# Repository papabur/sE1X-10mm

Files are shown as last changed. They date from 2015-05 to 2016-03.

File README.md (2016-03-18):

# sE1X-10mm
E1X (super) with lulz bed and 10mm smooth rods

First off, thank you Tjb1 for creating the E1X and for LoH's contributions such as making the required modifications to
allow for the Lulzbot 300x300mm heated bed and also for the upgraded 10mm smooth rod designs.

I have made a few modifications that I needed to allow for the lulzbot heated bed build to work on 10mm smooth rods(I was
the first one to actually do this upgrade, I ran int oa few snags..). The first one I ran into was the Y smooth rod holders
seemed to be roughly 2mm shy in the Y axis direction and I could not get the smooth rod to mount properly so I lengthened 
those, worked perfectly for me. Second, The added height from the 10mm smooth rods required a larger Y belt gripper, so I
made a padded version that adds 5mm to it so the belt runs smoothly.

I am selling kits of the sE1X on the Mobious website and will also be selling Crunch filament, along with MKS Sbase v1.2 smoothie-compatible control boards.

If your interested please visit http://mobious.org for more information.

(2016-03-18)UPDATE: 
1: Now featuring the Open X and the Open Y carriage designs that utilize 605zz bearings at 45 degree angles around a 10mm smooth rod for the smoothest ride imaginable!@
2: DUAL EXTRUDER VERSION NOW AVAILABLE!

I have made a new BoM for the sE1X broke down into 3 sections: Hardware - Printed Parts - Fasteners. I will have links
below.

Hardware and total costs: https://goo.gl/y2NCM3

Printed Parts:            https://goo.gl/c972AP

Fasteners:                https://goo.gl/F7yG47

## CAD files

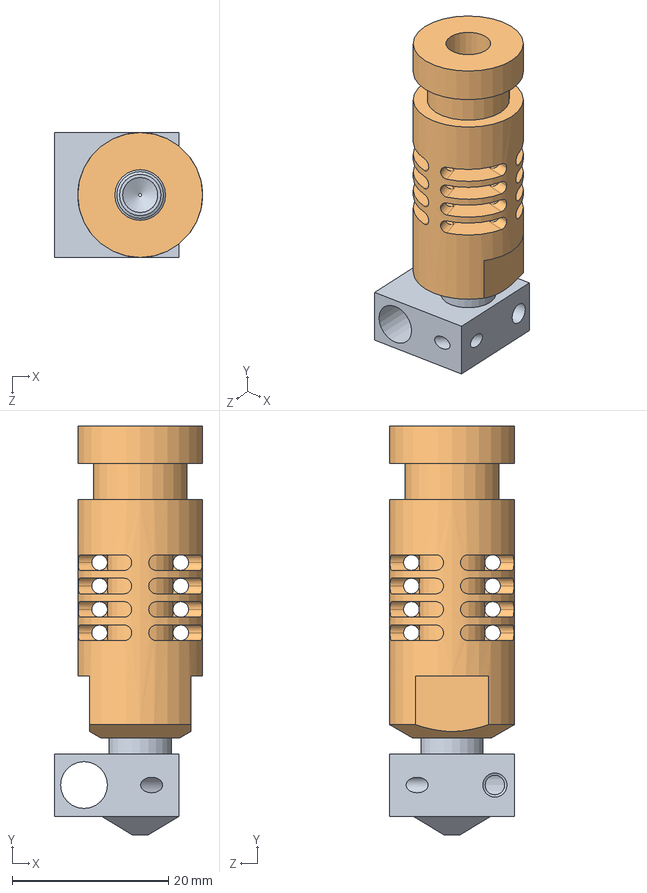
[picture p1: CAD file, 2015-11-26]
sE1X E Axis Printed Parts/JHead_Nozzle.SLDASM
19.0 x 52.4 x 16.0 mm
Part1^JHead_Nozzle
Part2^JHead_Nozzle

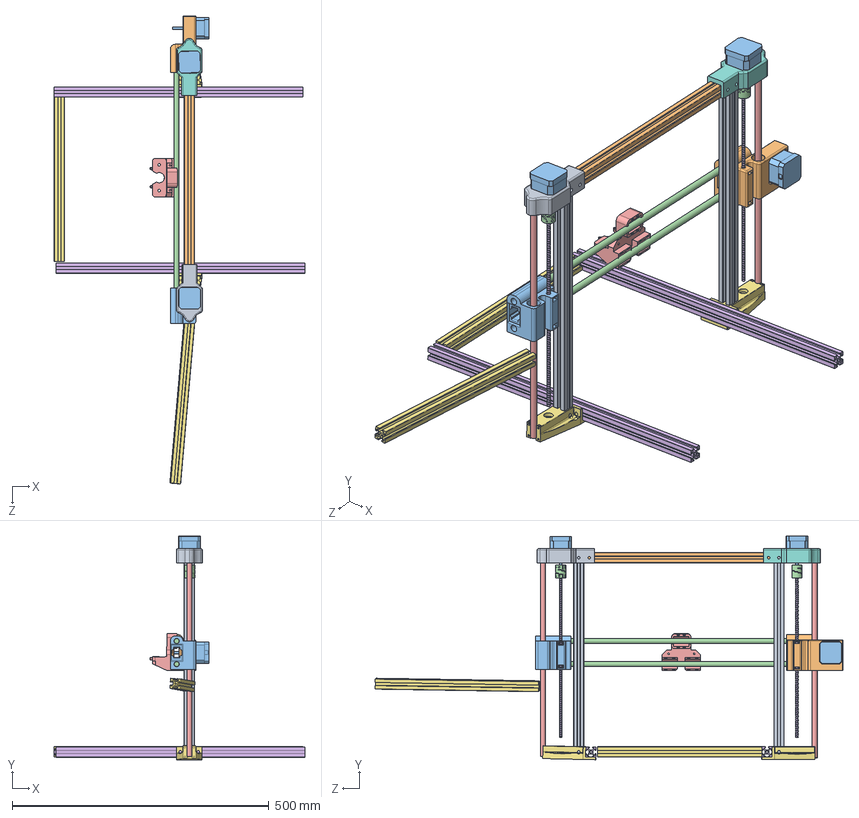
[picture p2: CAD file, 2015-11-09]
sE1X Gantry Assembly.SLDASM
488.2 x 435.6 x 911.8 mm
sE1X 398mm Z axis 2020 extrusion x 2
370mm X axis 2020 extrusion
nema17 x 3
5mm coupler x 2
sE1X 398mm 10mm smooth rod x 2
5mm threaded rod x 2
sE1X Z Axis bottom bracket x 2
sE1X Z Axis top motor bracket(mirrored)
sE1X Z Axis top motor bracket
sE1X X Axis Motor end
sE1X X idler end
sE1X 465mm 10mm smooth rod x 2
SE1X 10mm carriage(BOWDEN)
sE1X 485mm Z axis 2020 extrusion x 2
320mm X axis 2020 extrusion x 2

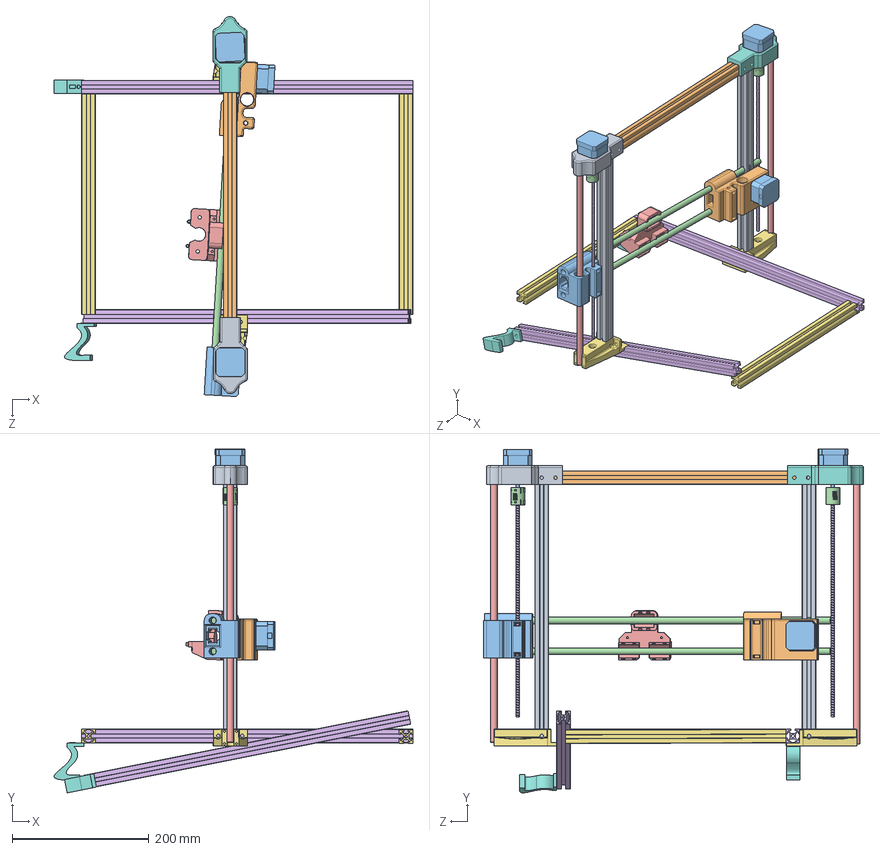
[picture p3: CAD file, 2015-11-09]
sE1X Complete Assembly.SLDASM
525.2 x 503.4 x 556.3 mm
sE1X 398mm Z axis 2020 extrusion x 2
370mm X axis 2020 extrusion
nema17 x 3
5mm coupler x 2
sE1X 398mm 10mm smooth rod x 2
5mm threaded rod x 2
sE1X Z Axis bottom bracket x 2
sE1X Z Axis top motor bracket(mirrored)
sE1X Z Axis top motor bracket
sE1X X Axis Motor end
sE1X X idler end
sE1X 465mm 10mm smooth rod x 2
SE1X 10mm carriage(BOWDEN)
sE1X 485mm Z axis 2020 extrusion x 2
320mm X axis 2020 extrusion x 2
Printer Supports -sE1X x 2

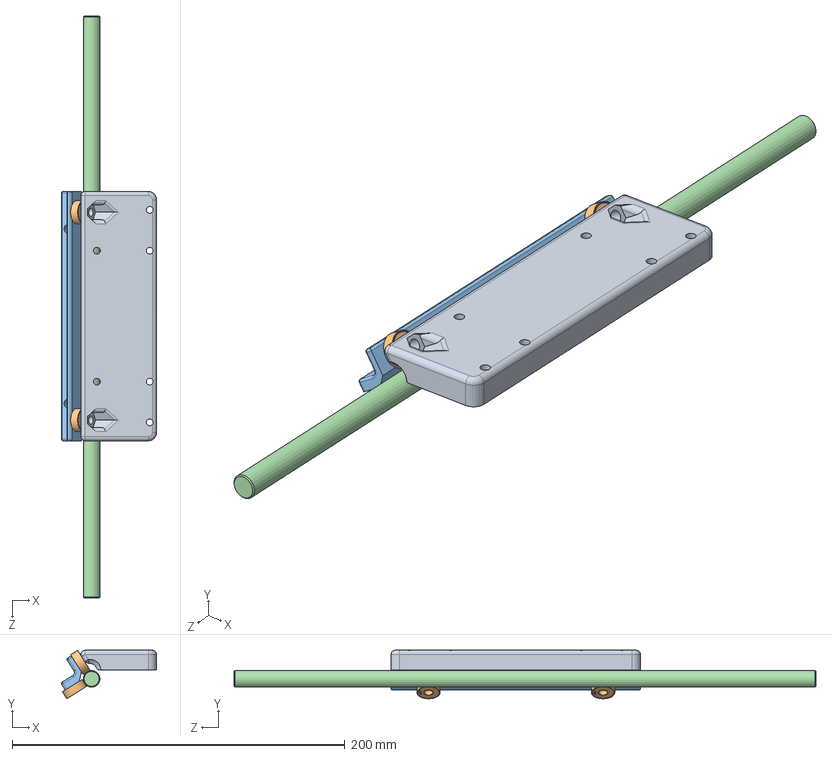
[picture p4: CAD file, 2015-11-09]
sE1X Y Axis Printed Parts/sE1X OpenY carriage ass.SLDASM
57.2 x 29.2 x 350.0 mm
sE1X OpenY carriage
605Z Ball bearing x 4
sE1X OpenY carriage side bracket(x2)
Z Axis 10mm smooth rod

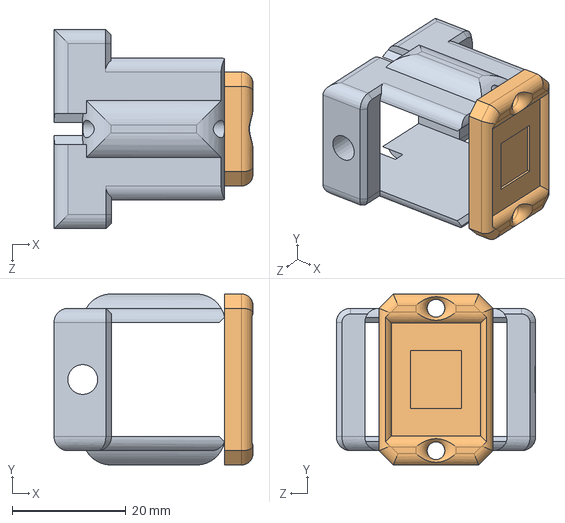
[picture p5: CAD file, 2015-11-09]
sE1X Y Axis Printed Parts/sE1X Y idler tensioner assembly.SLDASM
34.9 x 30.0 x 35.0 mm
sE1X Y idler
sE1X Y idler t-bracket

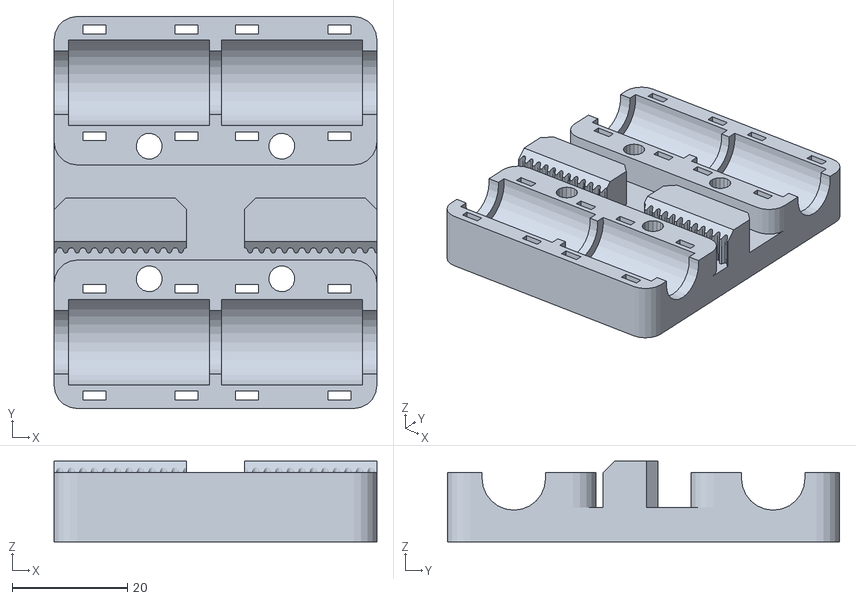
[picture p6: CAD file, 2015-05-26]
i3 Rework/X-CARRIAGE.stl
56.0 x 68.0 x 14.0

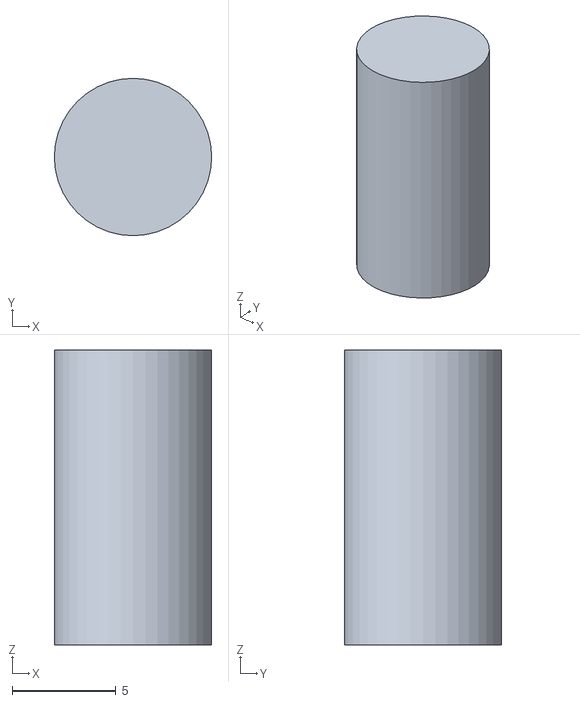
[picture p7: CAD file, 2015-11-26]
sE1X E Axis Printed Parts/Airtripper_Bowden_Extruder_BSP_Edition/axle.stl
7.60 x 7.60 x 14.2

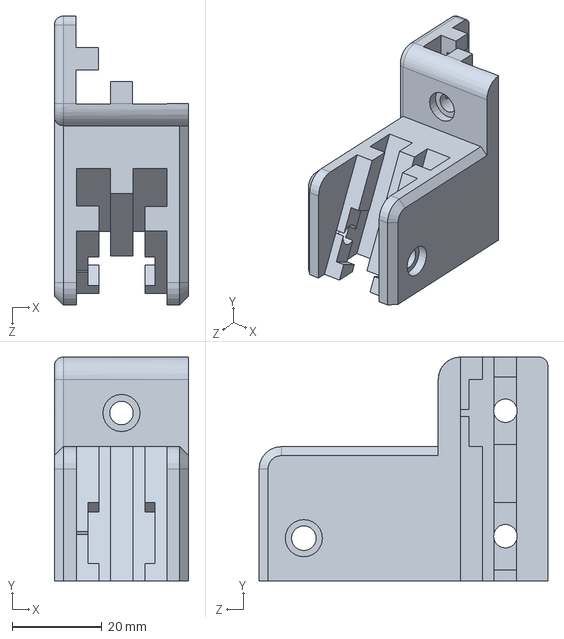
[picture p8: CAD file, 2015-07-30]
sE1X Gantry Supports/sE1X Gantry Support Z Axis Brace (L).SLDPRT
30.0 x 50.0 x 64.5 mm

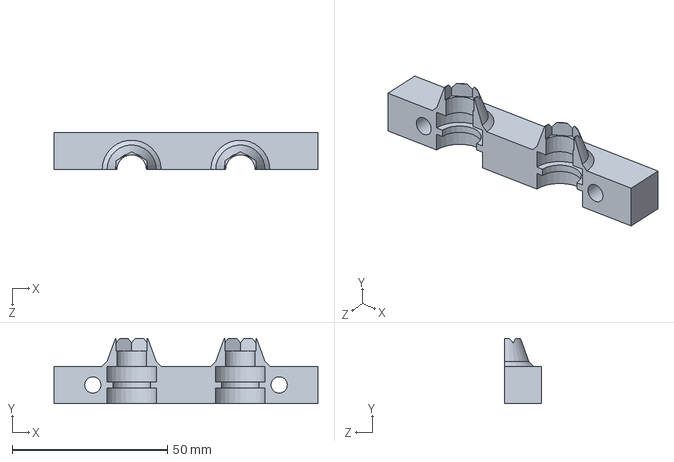
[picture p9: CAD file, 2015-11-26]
sE1X X Axis Printed Parts/OpenX Dual hotend bracket(1of2).SLDPRT
85.0 x 21.0 x 12.0 mm

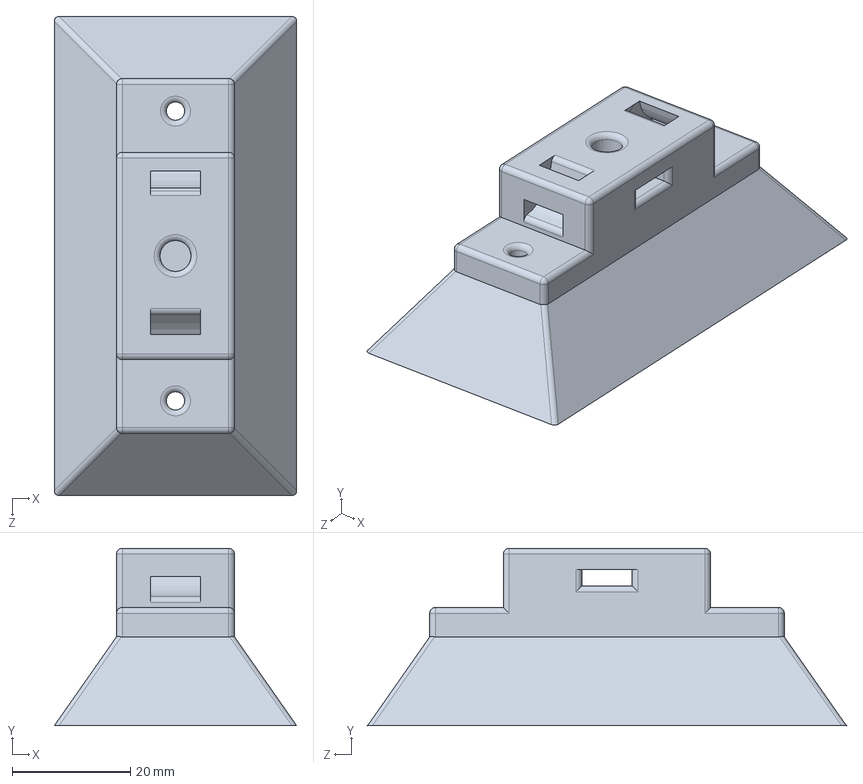
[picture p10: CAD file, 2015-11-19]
sE1X Y Axis Printed Parts/sE1X Y Belt Gripper.SLDPRT
41.0 x 30.0 x 81.0 mm

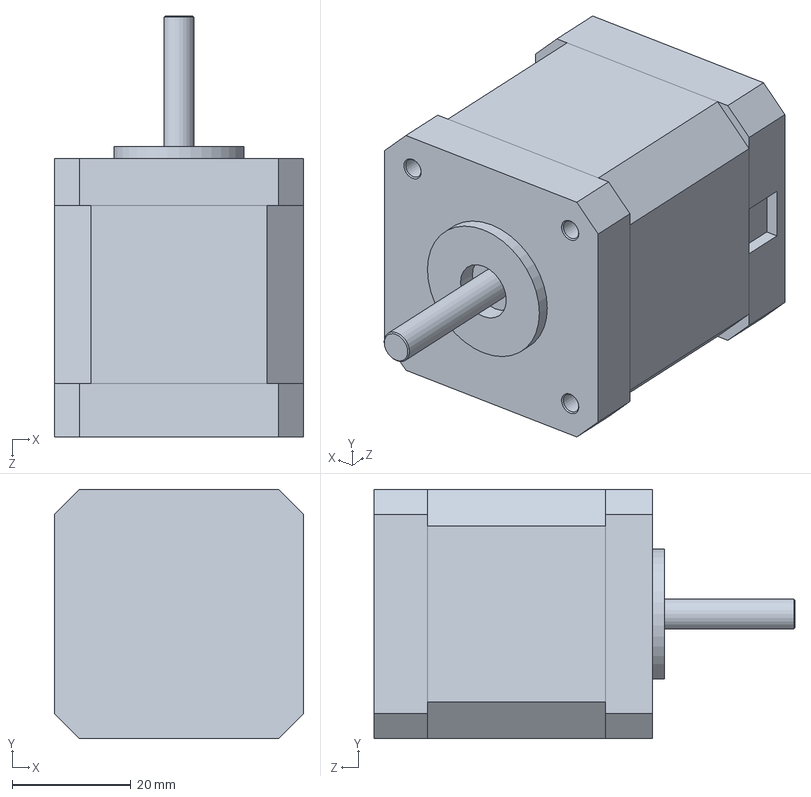
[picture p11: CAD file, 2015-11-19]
sE1X Z Axis Printed Parts/nema17.SLDPRT
42.0 x 42.0 x 71.0 mm

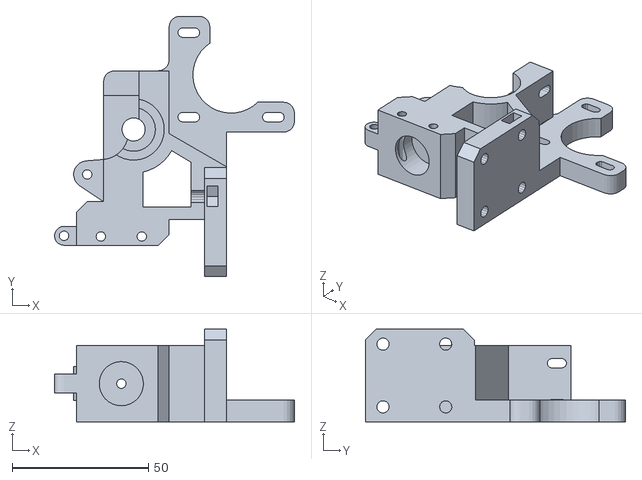
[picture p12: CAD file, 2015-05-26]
i3 Rework/BODY-EXTRUDEUR-WADE.stl
88.0 x 95.5 x 34.0

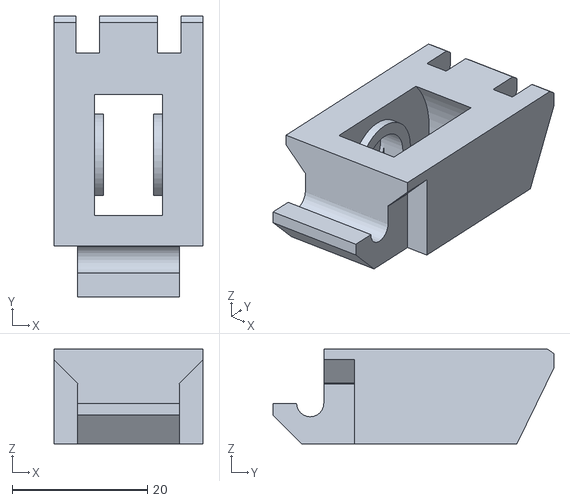
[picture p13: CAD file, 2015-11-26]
sE1X E Axis Printed Parts/Airtripper_Bowden_Extruder_BSP_Edition/idler.stl
22.0 x 41.5 x 14.0

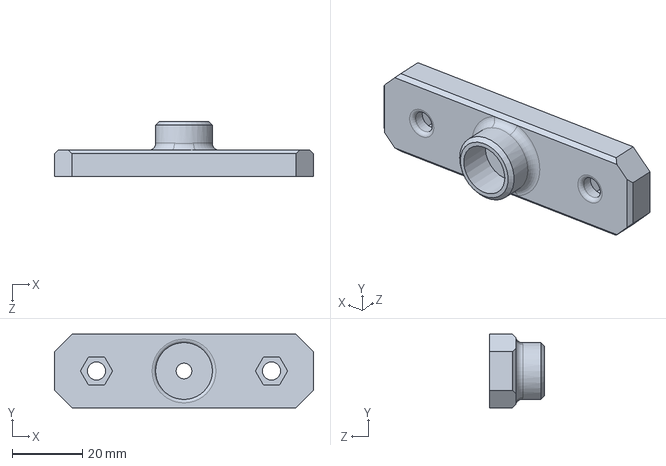
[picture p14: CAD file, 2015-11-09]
sE1X E Axis Printed Parts/se1x sptc hotend airtrip bracket.SLDPRT
74.0 x 21.0 x 15.7 mm

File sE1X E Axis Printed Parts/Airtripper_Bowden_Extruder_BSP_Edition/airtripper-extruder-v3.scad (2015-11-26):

// Airtripper's Bowden 3D Printer Extruder Revision 3 bsp
// by Airtripper May 2012
// Copyright © 2012 - 2013 Airtripper
// airtripper.com
// It is licensed under the Creative Commons - GNU GPL license. 
// Last edit: 05/09/2013





// What part do you want to view?

preview_part = 7; // [1:Extruder,2:Idler,3:Idler with brim,4:Strut,5:Axle,6:Tube Bracket,7:All Parts]


// *****************************************************

if (preview_part == 1) {
	translate([0,0,0]) rotate([0,0,270]) extruder_block();
}
if (preview_part == 2) {
	extruder_idler_608z();
} 
if (preview_part == 3) {
	idler_and_flange();
}
if (preview_part == 4) {
	support_strut();
} 
if (preview_part == 5) {
	axle_8mm();
}
if (preview_part == 6) {
	translate([15,-15,0]) rotate([0,0,90]) tube_bracket();
}
if (preview_part == 7) {
	translate([0,-20,0]) rotate([0,0,270]) extruder_block();
	translate([20,16,0]) rotate([0,0,90]) extruder_idler_608z(); //idler_and_flange();
	translate([22,35,0]) rotate([0,0,0]) support_strut();
	translate([-10,10,0]) rotate([0,0,0]) axle_8mm();
	translate([-36,8,0]) rotate([0,0,0]) tube_bracket();
} 
if (preview_part == 8) {
	translate([0,-10,0]) rotate([0,0,270]) extruder_block();
	translate([-0,22,0]) rotate([0,0,0]) axle_8mm();
}
if (preview_part == 9) {
	translate([0,-8,0]) rotate([0,0,90]) extruder_idler_608z(); //idler_and_flange();
	translate([0,10,0]) rotate([0,0,0]) support_strut();
} 



// ************** Idler with Flange ***********************

module idler_and_flange() {
	extruder_idler_608z();
	difference() {
		union() {
			difference() {
				translate([0,0,0.5]) color("red") cube([36,55,1], center=true);
				translate([0,0,-0.1]) scale([1.1,1.1,1.1]) extruder_idler_608z();
			}
			for(r=[1:5]) {
				translate([0,r*70/10-22,0.5]) cube([30,1,1], center=true);
				translate([r*64/10-19,0,0.5]) rotate([0,0,90]) cube([50,1,1], center=true);
			}
		}
		union() {
			translate([0,0,0.5]) color("red") cube([12,28,2], center=true);
			translate([0,0,0.5]) color("red") cube([18,10,2], center=true);
		}
	}


}



// ##########################################################

module axle_8mm() {
	cylinder(14.25,r=3.80, $fn=40);
	// Support flange while printing
//	translate([-5,-0.5,0]) cube([10,1,0.5]);
//	translate([-0.5,-5,0]) cube([1,10,0.5]);
//	difference() {
//		cylinder(0.5,r=10, $fn=40);
//		translate([0,0,-1]) cylinder(3,r=5, $fn=40);
//	}
}


// ##########################################################

//extruder_idler_608z();

module extruder_idler_608z() {
	difference() {
		union() {
			difference() {
				translate([0,0,7]) cube([22,42,14], center = true);
				// Bearing housing
				//#translate([-6,0,8]) cube([10,50,20], center = true);
				translate([0,0,1]) cube([10,24,10], center = true);
				translate([-5,0,6]) rotate([0,90,0]) cylinder(10,r=12, $fn=60);
			}
			// Axle spacer
			translate([-8,0,6]) rotate([0,90,0]) cylinder(16,r=6, $fn=40);
			translate([0,0,3]) cube([16,12,6], center = true);
		}
		union() {
			// Bearing axle cut-out
			translate([-7.75,0,6]) rotate([0,90,0]) cylinder(15.5,r=4.25, $fn=40);
			translate([0,0,2]) cube([14.2,8.5,8], center = true);
			translate([-4.5,0,0]) rotate([0,20,0]) cube([6,8.5,8], center = true);
			translate([4.5,0,0]) rotate([0,-20,0]) cube([6,8.5,8], center = true);
			translate([-3.7,0,6]) rotate([0,90,0]) cylinder(7.4,r=12, $fn=60);
			// hook
			translate([-12,-15.5,6]) rotate([0,90,0]) cylinder(24,r=2, $fn=25);
			translate([0,-18.5,11]) cube([24,10,10], center = true);
			translate([9.5,-17,1]) cube([4,16,16], center = true);
			translate([-9.5,-17,1]) cube([4,16,16], center = true);
			translate([0,-21,0]) rotate([45,0,0]) cube([24,6,10], center = true);
			translate([-11,-12,9.6]) rotate([0,135,0]) cube([4,6,6], center = true);
			translate([11,-12,9.6]) rotate([0,45,0]) cube([4,6,6], center = true);
			// Bolt slots
			translate([6,20,7]) cube([3.5,10,16], center = true);
			translate([-6,20,7]) cube([3.5,10,16], center = true);
			translate([0,24,7]) rotate([154,0,0]) cube([24,10,26], center = true);
			translate([0,26.5,25]) rotate([145,0,0]) cube([24,10,26], center = true);
			translate([0,25.5,7]) cube([22,10,16], center = true);
			//Padding
			//translate([-9,-17,7]) cube([6,10,16], center = true);
		}
	}

}


// #########################################################

// Revision 3b

module extruder_block() {
	difference() {
		union() {
			// Extruder base
			translate([0,0,1.5]) cube([42,42,3], center = true);

			// Bearing supports between screw columns and shaft bearing
			rotate([0,0,45]) translate([0,11,13]) cube([3,22,26], center = true);
			rotate([0,0,315]) translate([0,-11,13]) cube([3,22,26], center = true);
			difference() {
				translate([-3,0,22]) cylinder(8,r1=4, r2=4, $fn=50, center = true);
				rotate([0,90,0]) translate([-17,0,-10]) cylinder(8,r=4, $fn=50);
			}
			difference() {
				translate([0,0,3]) cylinder(22,r1=13.5, r2=6.3, $fn=100);	// rev. 3
				rotate([0,0,45]) translate([8,0,13]) cube([15,30,26.5], center = true);	// rev. 3
				rotate([0,0,315]) translate([8,0,13]) cube([15,30,26.5], center = true);	// rev. 3
			}
			// M3 Screw columns for stepper attachment
			translate([-15.5,15.5,0]) cylinder(26,r=4, $fn=50);	// rev. 3
			translate([-15.5,15.5,18]) cylinder(8,r1=4,r2=6, $fn=50);	// rev. 3
			translate([-15.5,-15.5,0]) cylinder(23.5,r=4, $fn=50);	// rev. 3
			translate([-15.5,-15.5,17.5]) cylinder(6,r1=4,r2=5, $fn=50);	// rev. 3
			translate([15.5,-15.5,3]) cylinder(1.5,r=3.5, $fn=50);	// rev. 3

			// fixing plate
			difference() {
				translate([-20,0,10]) cube([3,74,20], center = true);
				union() {

					// fixing plate cutout
					translate([-20,0,12]) cube([6,30,18], center = true);
					translate([-20,37,0]) rotate([45,0,0]) cube([6,16,7], center = true);
					translate([-20,-37,0]) rotate([135,0,0]) cube([6,16,7], center = true);
					translate([-20,37,20]) rotate([135,0,0]) cube([6,16,7], center = true);
					translate([-20,-37,20]) rotate([45,0,0]) cube([6,16,7], center = true);
					// M6 bolt holes
					translate([-23,30.5,10]) rotate([0,90,0]) cylinder(6, r=3.5, $fn=25);
					translate([-23,-30.5,10]) rotate([0,90,0]) cylinder(6, r=3.5, $fn=25);
				}
			} // End of fixing plate
		}
		union() {
			// Stepper shaft, gear insert and bearing cut-out
			translate([0,0,9.8]) cylinder(20,r1=13, r2=5, $fn=50, center = true);	// rev. 3
			translate([0,0,22]) cylinder(5,r=5, $fn=50, center = true);
			translate([0,0,27]) cylinder(8	,r=4, $fn=50, center = true);
			translate([0,0,25.5]) cylinder(2,r1=5, r2=4, $fn=50, center = true);
			translate([0,0,10.5]) cylinder(8	,r=7, $fn=100);	// rev. 2
			translate([0,0,18.5]) cylinder(3.5,r1=7, r2=3.5, $fn=50);	// rev. 2

			// Reduce wall and screw shaft for strut placement
			translate([-15.5,-15.5,23.5]) cylinder(5,r=3, $fn=30);
			translate([-12.5,-15.5,25.5]) cube([12,9,4], center = true);
			translate([-11.4,-11.4,27.9]) rotate([25,0,315]) cube([5,10,5], center = true);

			// M3 screw holes
			for(r=[1:4]) {
				rotate([0,0,r*360/4]) translate([15.5,15.5,-1]) cylinder(40,r=1.75, $fs=.1);
			}
			translate([-15.5,15.5,22.1]) cylinder(4,r=3.3, $fn=30);	// rev. 3
			translate([15.5,15.5,1.5]) cylinder(4,r=3.25, $fs=.1);	// rev. 3
		}
	}
	// Filament in-feed bracket
	difference() {
		union() {
			translate([8.75,-20,3]) rotate([0,0,90]) infeed_block();	// rev. 3
			translate([-12,-17,3]) rotate([0,0,-12]) cube([14,2,16]);	// rev. 3
		}
		//%translate([4.8,-8,15]) rotate([90,0,0]) cylinder(18, r=1.3, $fn=25);	// rev. 2, 3
		//%translate([4.8,-21,15]) rotate([90,0,0]) cylinder(8, r1=1.1, r2=4, $fn=25);	// rev. 3
		//#translate([0,0,10]) cylinder(20,r1=13, r2=5, $fn=50, center = true);
		// #translate([5,-10,13]) cube([10,6,20], center = true);	// rev. 2, 3
	}
	// Bowdon out-feed tube holder
	difference() {
		union() {
			translate([4.8,14,13]) cube([8,14,26], center = true);
			//translate([4.8,25,10]) cube([14,8,20], center = true);	// rev. 3, 3b
			translate([-5.5,12.5,13]) cube([13.5,3,26], center = true);	// rev. 3
			// translate([0,12.5,13]) cube([2,3,26], center = true);	// rev. 3
			// translate([-4.5,12.5,4]) cube([13.5,3,3], center = true);	// rev. 3
			// #translate([0,17,17]) cube([2,6,20], center = true);	// rev. 3
			translate([3.3,21,13]) cube([11,3,26], center = true);	// rev. 3
			translate([11.8,17.5,0]) rotate([0,0,90]) bsp_push_fit();
		}
		union() {
			// Tube and filament holes
			//#translate([4.8,36,15]) rotate([90,0,0]) cylinder(16, r=2.25, $fn=25);	// 3b
			translate([4.8,24,15]) rotate([90,0,0]) cylinder(20, r=1.15, $fn=25);	// rev. 2, 3
			translate([5.3,16,15]) rotate([90,0,5]) cylinder(10, r1=0.4, r2=3, $fn=25);	// rev. 3

			// Insert and idler clearance
			translate([0,0,9.9]) cylinder(20,r1=13, r2=5, $fn=50, center = true);	// rev. 3
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

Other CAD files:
sE1X Gantry Supports/sE1X Gantry Support Z Axis Brace (R).SLDPRT
sE1X X Axis Printed Parts/OpenX Carriage (sE1X_15)(1of3).SLDPRT
sE1X Y Axis Printed Parts/Printer Supports -sE1X.SLDPRT
sE1X Z Axis Printed Parts/5mm threaded rod.SLDPRT
ChrisM21 10mm star fit.SLDPRT
i3 Rework/BODY-EXTRUDEUR-WADE-1.75mm-with-support.stl
i3 Rework/EXTRUDER-IDLER-avec-guide.stl
i3 Rework/WADE-BIG-GEAR.stl
i3 Rework/WADE-SMALL-GEAR.stl
sE1X E Axis Printed Parts/AO_Fan_Mount_v1.2.STL
sE1X E Axis Printed Parts/Airtripper sE1X carriage ptc bracket.SLDPRT
sE1X E Axis Printed Parts/Airtripper sE1X carriage ptc bracket.STL
sE1X E Axis Printed Parts/Airtripper swivel mount.SLDPRT
sE1X E Axis Printed Parts/Airtripper swivel mount.STL
sE1X E Axis Printed Parts/Airtripper_Bowden_Extruder_BSP_Edition/air-bsp.stl
sE1X E Axis Printed Parts/Airtripper_Bowden_Extruder_BSP_Edition/pipe.stl
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

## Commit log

2015-05-10 10mm E1X
    A few modifications to allow for 10mm smooth rod on the E1X with the
    lulz bed.
    [lulz-belt-gripper_5mm-pad.stl, y-rod-holder-1.75mm add.stl]
2015-05-26 i3 rework stls added
    Added the i3 rework x carriage along with the wades extruder to link to
    tutorial.
    [BODY-EXTRUDEUR-WADE-1.75mm-with-support.stl, BODY-EXTRUDEUR-WADE.stl, EXTRUDER-IDLER-avec-guide.stl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]
2015-06-04 AO Shroud
    Shroud for the Hexagon AO hotend
    [AO_Fan_Mount-2.STL]
2015-06-18 sE1X lower frame corner brackets
    New corner brackets for the lower frame assembly, fully printable and
    sturdy.
    [sE1X corner brackets v2.SLDPRT, sE1X corner brackets v2.STL]
2015-06-22 Top and Bottom corner brackets
    The latest version of my new sE1X corner brackets
    [sE1X corner brackets(BOTTOM).STL, sE1X corner brackets(TOP).STL]
2015-06-22 remove old corners
    removed the old cornerb rackets
    [sE1X corner brackets v2.SLDPRT, sE1X corner brackets v2.STL]
2015-06-28 sE1X parts
    Gantry support, extrusion extension
    [150mm 2020 extrusion extension.SLDPRT, 150mm 2020 extrusion extension.STL, AO_Fan_Mount_v1.2.STL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]
2015-06-30 se1x corner bracket top sldprt
    se1x solidpart
    [sE1X corner brackets(TOP).SLDPRT]
2015-06-30 bed corner brackets
    heated bed corners
    [bed_corner_extended_and_sized.STL]
2015-07-10 Fixxed manifolds on Z axis braces
    Ran the Z Axis braces for gantry support through netfabb cloud to make
    everything manifold. still need to rotate parts -90 in slic3r to lay
    flat.
    [Z Axis Brace (left) v1.2_fixed.STL, Z Axis Brace(right)_v1.2_fixed.STL]
2015-07-11 Dizingof Yoda stls
    Uploaded the Dizingof yoda stl designs
2015-07-13 sE1X 8mm carriage
    Newly made 8mm carriage, belt holder is sep. file
    [SE1X 8mm carriage.SLDPRT, SE1X 8mm carriage.STL]
2015-07-13 updated carriage
    belt holder added
    [SE1X 8mm carriage.SLDPRT, SE1X 8mm carriage.STL]
2015-07-13 Carriage edit - fixed version upload
    Noticed a few issues with the carriage involving faces around extruder
    mount area, fixed. also uploaded a fixed version which I ran through
    netfabb cloud.
    [SE1X 8mm carriage.SLDPRT, SE1X 8mm carriage.STL, SE1X 8mm carriage_fixed.STL]
2015-07-13 correction to carriage files
    derped saving file..refixed
    [SE1X 8mm carriage.STL, SE1X 8mm carriage_fixed.STL]
2015-07-13 fixed version of carriage
    ran the carriage through netfabb cloud again
    [SE1X 8mm carriage_fixed.STL]
2015-07-13 071315 - Z axis top motor mount - 2020 extrusion
    Made the Z axis top motor mount today and found a 2020 extrusion .sldprt
    to use as default 2020 extrusion
    [2020 Extrusion.SLDPRT, SE1X 8mm carriage.SLDPRT, Z Axis top motor mount.STL]
2015-07-14 Updated Z top motor mount / gantry assembly
    z top motor mount update and gantry assembly(work in progress)
    [Z Axis top motor mount.STL, sE1X Gantry.SLDASM]
2015-07-14 ~$ file for 8mm carraige
    not sure what this is..
2015-07-27 Slim lined Motor mounts/Updated Assembly
    I made the Z motor mounts slimmer where it meets the extrusions, to fit
    m5-10s and rounded off more around the 10mm smooth rod hole to use less
    plastic. Updated assembly with new changes.
    [Mech mod mobious case.SLDPRT, Z Axis top motor mount(mirrored).STL, Z Axis top motor mount.STL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]
2015-07-30 073015 - All recent changes/updates
    Gantry support, sE1X v1.5 files (New Z and X axis design files)
    [2020 Extrusion.SLDPRT, SE1X 8mm carriage.SLDPRT, Y Axis Brace Clamp.SLDPRT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]
2015-07-30 Fixed name
    [sE1X heated bed corners.STL]
2015-07-30 10mm carriage add
    First 10mm carriage.
    [SE1X 10mm carriage.SLDPRT, SE1X 10mm carriage.STL]
2015-08-03 New x motor end
    Adjusted some things to allow for different Nema 17s to fit.
    [sE1X X Axis Motor end.STL]
2015-08-03 new x axis motor end
    Fixed the nema 17 mount for the se1x x axis motor end
2015-08-12 Reptile Hide
    [Sollys Hide.SLDPRT, Sollys Hide.STL]
2015-08-16 belt tensioner stl
    [sE1X X Idler belt tensioner.STL]
2015-08-16 sollys hide extension
    [Sollys Hide Mid section.SLDPRT, Sollys Hide Mid section.STL]
2015-08-20 bowden carriage
    updated carriage to fit better with bowden extruder, dont forget to add
    ptf part!
    [SE1X 10mm carriage(BOWDEN).SLDPRT, SE1X 10mm carriage(BOWDEN).STL]
2015-08-23 Fixxed sE1X bowden carriage
    Made some changes to improve the carriage. Belt brackets are now a
    seperate part which will bolt onto the back of the carriage
    [SE1X 10mm carriage(BOWDEN).SLDPRT, SE1X 10mm carriage(BOWDEN).STL, sE1X 10mm extruder belt bracket.SLDPRT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]
2015-08-23 belt bracket mirrored added
    Needed a Left and Right for the belt bracket on the X carriage. Works
    great with m3-12's
    [sE1X 10mm extruder belt bracket mirrored.SLDPRT, sE1X 10mm extruder belt bracket mirrored.STL]
2015-08-31 Organzied Directory
    Moved all files to new folders to clean things up and make it easier for
    others to find the right files.
    [AO_Fan_Mount_v1.2.STL, Airtripper sE1X carriage ptc bracket.SLDPRT, Airtripper sE1X carriage ptc bracket.STL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]
2015-11-09 X Axis tensioner update
    Made a couple corrections to the x axis belt tensioner arm/
    [(x4)sE1X Y axis 10mm smooth rod holders.stl, 605Z Ball bearing.SLDPRT, ChrisM21 10mm star fit.SLDPRT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]
2015-11-09 Fixed Tensioner and Carriage ziptie holes(removed M)
    in title.
    [SE1X 10mm carriage(BOWDEN).SLDPRT, SE1X 10mm carriage(BOWDEN).STL, sE1X X Idler belt tensioner.SLDPRT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]
2015-11-19 11-19-2015
    new X carriage design, "The sE1X OpenX Mantix". Fixxed belt tensioner.
    rearranged some extra parts such as extrusions for the assemblies, to
    their designated axis folder..
    [2020 Extrusion.SLDPRT, 330mm X axis 2020 extrusion.SLDPRT, 370mm X axis 2020 extrusion.SLDPRT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]
2015-11-26 2015-11-26 - openX carriage and dual extrude mounts
    Carriage and Extruder updates
    [JHead_Nozzle.SLDASM, OpenX Carriage (sE1X_15)(1of3).SLDPRT, OpenX Carriage (sE1X_15)(1of3).STL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]
2016-01-16 pulley axis improvement
    Modified sE1X X Idler belt tensioner to better accommodate belt.
    Increased space to allow belt to ride on pulley.
    [sE1X X Idler belt tensioner.STL]
2016-03-18 Updated info
    Added Update info regarding OpenX/OpenY designs and Dual Extrusion.
